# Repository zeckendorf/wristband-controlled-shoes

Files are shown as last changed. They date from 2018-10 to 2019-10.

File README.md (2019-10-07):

# Remote Controlled Shoes

These exist with [some ubiquity](https://www.amazon.com/s?k=led+shoes+with+remote&ref=nb_sb_noss), but at the prompting of a friend I thought it might be fun to design a system that would work more flexibly in different form factors. Ultimately, one device sits as a combination BLE beacon and peripheral that can pair with a phone and transmit the LED state via BLE  advertising packets. 

## Files

**`ble_beacon_remote.ino`**

Device acting as BLE remote that scans for the beacon. Ordinarily this pairs with peripherals, but in this case simply scans for advertising packets, extracts the UUID, and if it is a match for its remote, will sync its state. Deployed to any number of synced devices beyond shoes, e.g. LED headphones synced with music.

**`ble_beacon_origin.ino`**

Device acting as the BLE beacon &mdash; pairs with a control phone as a peripheral to set the button states, and then upon button presses will adjust its state and transmit this information via the BLE beacon `minor` value. BLE beacon architecture is as follows:

* `uuid`: 16-byte identifier for all devices in a given family (e.g. LED shoes). In this case, the first 8-bytes represent the device family and the  second 8-bytes are a unique identifier for this pair.

* `major`: 2-byte device category of paired state (i.e. two shoes, 16 headphones, whatever)
* `minor`: 2-byte system color state

## In Action

*Cycling Through Basics:*

its working

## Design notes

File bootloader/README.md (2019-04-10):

## Arduino Bootloader for NRF52

**Source:**

- [Adafruit Arduino Bootloader Repo](https://github.com/adafruit/Adafruit_nRF52_Arduino_Bootloader)

- [Adafruit NRF52 Arduino Repo](https://github.com/adafruit/Adafruit_nRF52_Arduino)

Thanks eternally for their work getting this chipset in the hands of the people.

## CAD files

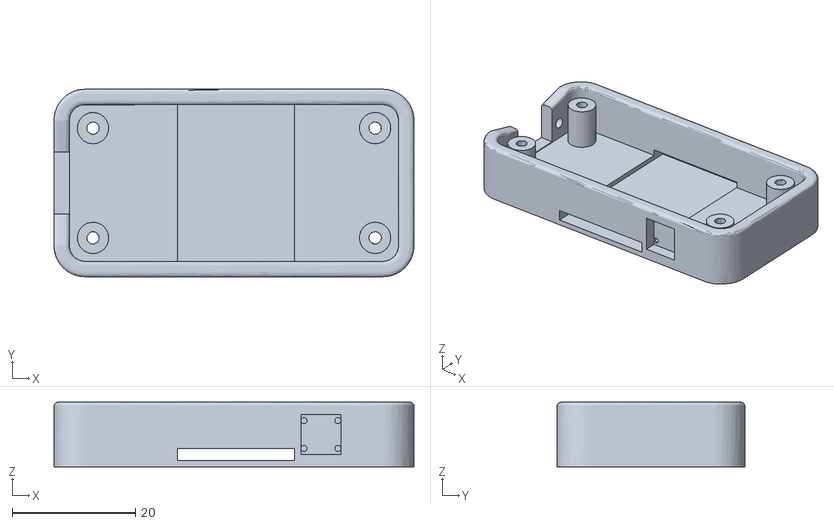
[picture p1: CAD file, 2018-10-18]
design/enclosure/v0/wristband-mount.stl
58.3 x 30.4 x 10.5

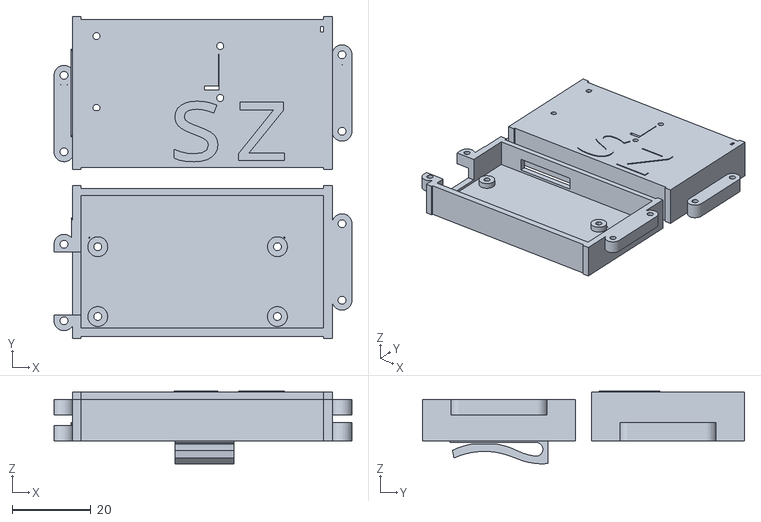
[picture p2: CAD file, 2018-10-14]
design/enclosure/v0/shoe-light-box.stl
75.8 x 82.0 x 18.5

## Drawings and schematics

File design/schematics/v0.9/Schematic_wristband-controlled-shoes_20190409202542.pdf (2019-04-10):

PP3300

PP3300

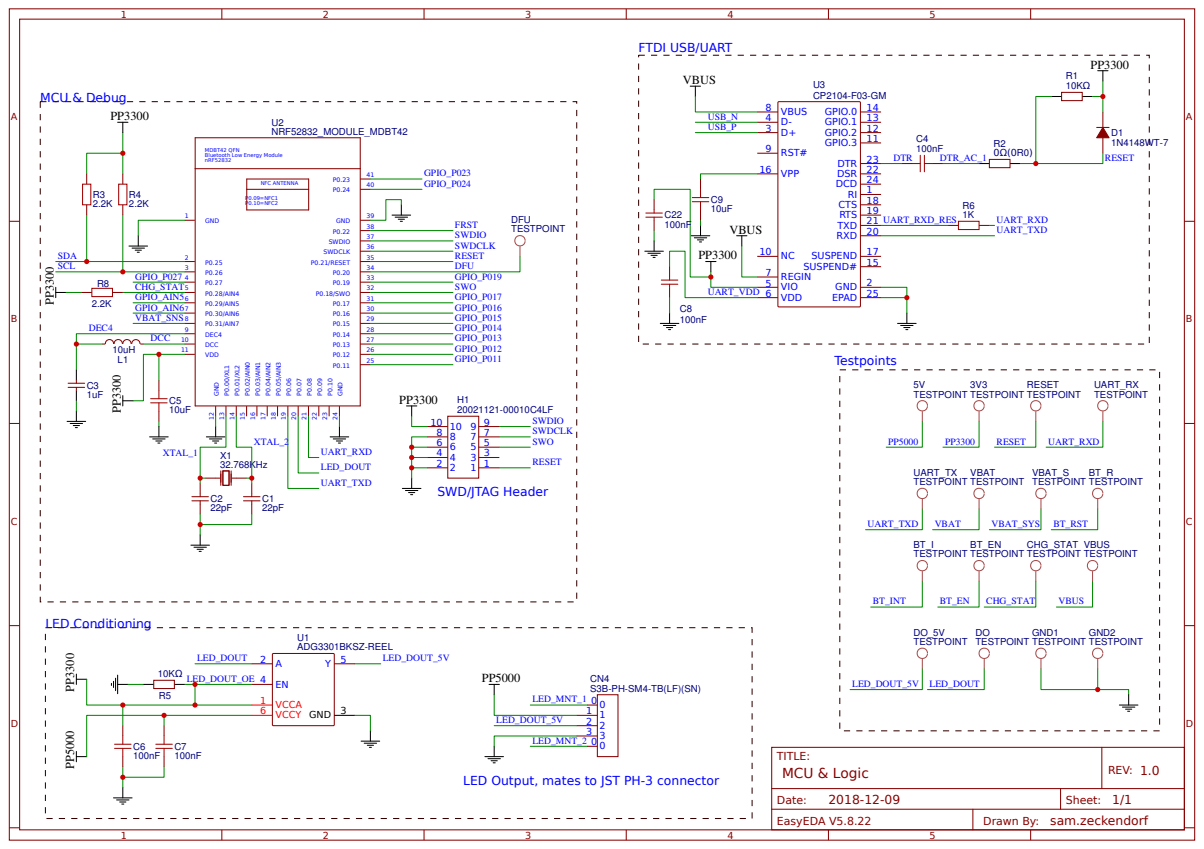
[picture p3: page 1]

24 P0.11 25 P0.12 26 P0.13 27 P0.14 28 P0.15 29 P0.16 30 P0.17 31 P0.18/SWO 32 P0.19 33 P0.20 34 P0.21/RESET 35 SWDCLK 36 SWDIO 37 P0.22 38 GND 39

LED Output, mates to JST PH-3 connector

### VBUS

### VBAT

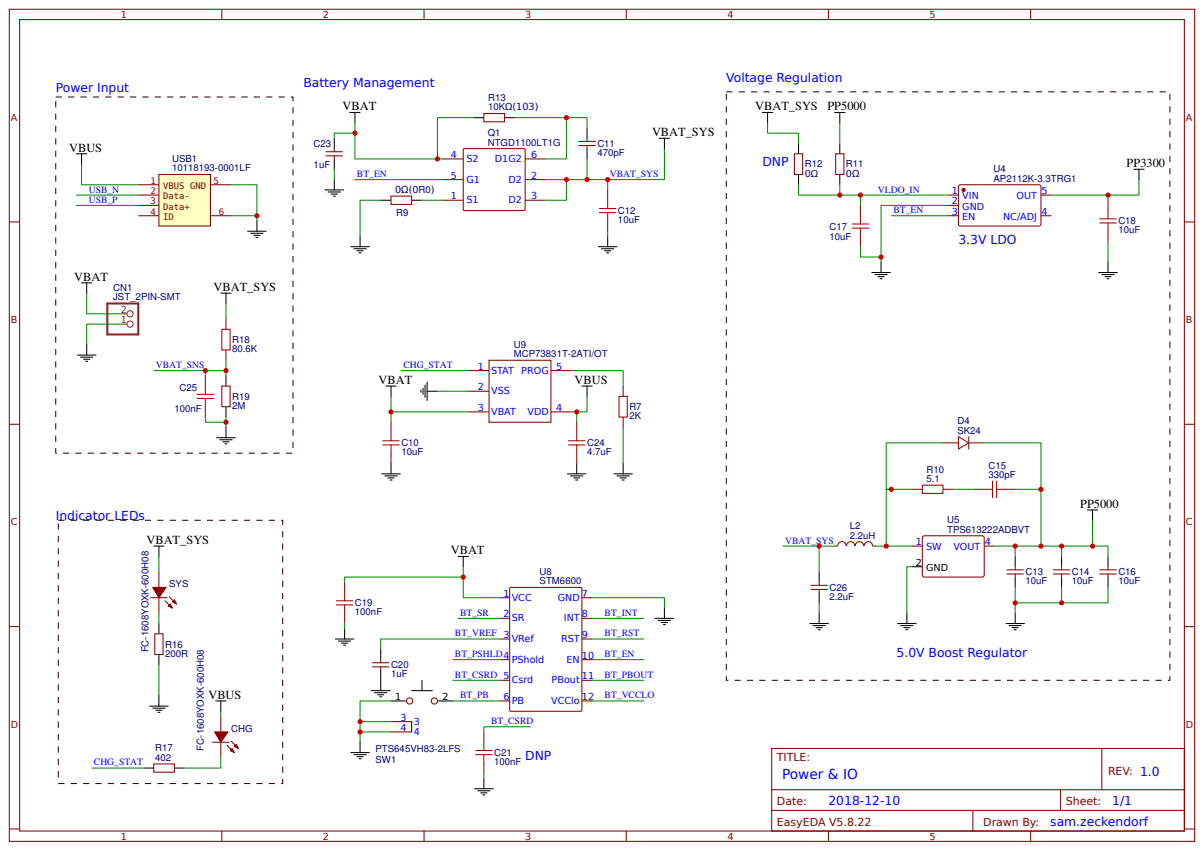
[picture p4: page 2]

Voltage Regulation Battery Management Power Input

Indicator LEDs FC⁻¹⁶⁰⁸YOXK⁻⁶⁰⁰H⁰⁸

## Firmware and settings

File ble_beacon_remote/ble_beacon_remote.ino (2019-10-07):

/*********************************************************************
Author: Sam Zeckendorf
  Date: 10/18/18
  File: ble_beacon_remote.ino

Uses an NRF52 module to sync states with 
 a BLE beacon and illuminate a string of WS2812 RGB LEDs
*********************************************************************/

/* TODO:
    - Get rid of delays in animations by using millis() and frame time modulus
    -
*/

// External libraries from Adafruit
#include <bluefruit.h>
#include <Adafruit_NeoPixel.h>

// Constant definitions -- these offsets within the ble advertising packet 
// are described here (page 10): http://www.ti.com/lit/an/swra475a/swra475a.pdf
// and also here: https://os.mbed.com/blog/entry/BLE-Beacons-URIBeacon-AltBeacons-iBeacon/
#define PIN 7
#define UUID_SIZE 16     //bytes
#define UUID_OFFSET 9    //bytes (Beacon Prefix: 3B flags + 2B header + 2B company ID + 1B secondary ID + 1B length = 9B)
#define ADV_SCAN_SIZE 31 //bytes
#define MINOR_OFFSET 28  //bytes
#define MINOR_SIZE 2     //bytes
#define NUM_LEDS 110
#define PIN_CHG_STAT 28  // digital state of charger pin
#define PIN_VBAT_SNS A7   // analog input of vbat sns 7

// for color data
Adafruit_NeoPixel strip = Adafruit_NeoPixel(NUM_LEDS, PIN, NEO_GRB + NEO_KHZ800);

// state for color
uint16_t state;
bool charging;

// mathematical operations
float adc_voltage;
float vbat_scale;
float vbat;

// time in millis in state
unsigned long time_in_state;
unsigned long duration_in_state; 
unsigned long frames_in_state;

// id of beacon, to be generated via: https://www.uuidgenerator.net/
uint8_t target_uuid[UUID_SIZE] = 
{ 
    0xFF, 0xFF, 0xFF, 0xFF, 0xFF, 0xFF, 0xFF, 0xFF, 
    0xFF, 0xFF, 0xFF, 0xFF, 0xFF, 0xFF, 0xFF, 0xFF, 
};

void setup()
{
  // set scaling
  vbat_scale  = 0.9612; // defined in hardware
  adc_voltage = 3.3;    // volts 
  
  // set up pin modes
  pinMode(PIN_CHG_STAT, INPUT_PULLUP);
  charging = !digitalRead(PIN_CHG_STAT);
  vbat     = measure_battery();
  
  // time setup
  time_in_state     = 0;
  duration_in_state = 0;
  frames_in_state   = 0;
  
  // LED setup
  strip.begin();
  strip.show();

  // BLE setup
  Serial.begin(115200);
  Serial.println("LED Shoe Listening for Wristband Beacon");
  Serial.println("-----------------------------------\n");
  
  // Initialize Bluefruit with maximum connections as Peripheral = 0, Central = 1
  // SRAM usage required by SoftDevice will increase dramatically with number of connections
  Bluefruit.begin(0, 1);
  Bluefruit.setName("LED_SHOE_0x0000");

  // Increase Blink rate to different from PrPh advertising mode
  //Bluefruit.setConnLedInterval(250);

  /* Start Central Scanning
   * - Enable auto scan if disconnected
   * - Interval = 100 ms, window = 80 ms
   * - Don't use active scan
   * - Start(timeout) with timeout = 0 will scan forever (until connected)
   */

  // set up scanner so we can monitor beacon packets
  Bluefruit.Scanner.setRxCallback(scan_callback);
  Bluefruit.Scanner.restartOnDisconnect(true);
  Bluefruit.Scanner.setInterval(160, 80); // in unit of 0.625 ms
  Bluefruit.Scanner.useActiveScan(true); // uses scan response packet as well
  Bluefruit.Scanner.start(0);            // 0 = Don't stop scanning after n seconds
}

float measure_battery()
{
  return analogRead(PIN_VBAT_SNS) / 1024.0 * adc_voltage / vbat_scale;
}

/**
 * Callback invoked when scanner pick up an advertising data
 * @param report Structural advertising data
 */
void scan_callback(ble_gap_evt_adv_report_t* report)
{
  // extract data from report (see nordic api)
  // https://developer.nordicsemi.com/nRF5_SDK/nRF51_SDK_v8.x.x/doc/8.0.0/s110/html/a00225.html
  uint8_t* data     = report->data;
  uint16_t rx_state = 0;
  // pull out uuid from data (slick array slicing using memcpy)
  uint8_t scanned_uuid[UUID_SIZE];
  memcpy(scanned_uuid, &data[UUID_OFFSET], sizeof scanned_uuid);
  
  if (arraysEqual(scanned_uuid, target_uuid, UUID_SIZE))
  { 
    // extract state
    rx_state = data[MINOR_OFFSET];

    // if the state changed, let's do something with it
    if (state != rx_state){
      state = rx_state;
      Serial.print("Shoe Beacon State Updated: ");
      Serial.print(state);
      Serial.print("\n-----------------------------\n");
      time_in_state = millis();
    }
  }
}

// helper function to determine if two arrays are equal
bool arraysEqual(uint8_t* a, uint8_t* b, int len)
{
  for(int i = 0; i < len; i++)
  {
    if(a[i] != b[i])
      return false;
  }
  return true;
}

// used for controlling LEDs
void loop()
{
  charging = !digitalRead(PIN_CHG_STAT);
  vbat     = measure_battery();
  
  // charging state machine
  if(charging){

    // low battery
    if (vbat < 2.7){
      red();
      delay(250);
      none();
      delay(250);
      return;
    }

    // medium battery
    if (vbat < 3.0){
      yellow();
      delay(250);
      none();
      delay(250);
      return;
    }
      // high battery
      green();
      delay(250);
      none();
      delay(250);
      return;
  }
  
  //Serial.println(duration_in_state);
  duration_in_state = millis() - time_in_state;
  if (state == 0x00)
  {
    none();
  }
  else if (state == 0x01)
  {
    red();
  }
  else if (state == 0x02)
  {
    green();
  }
  else if (state == 0x03)
  {
    blue();
  }
  else if (state == 0x04)
  {
    theaterChase(strip.Color(127, 127, 127), 25);
  }
  else if (state == 0x05)
  {
    rainbow(5, duration_in_state);
  }
}

/******************
 ***  LED Code! ***
 ******************/
void none() {
  uint16_t i;
    for(i=0; i<strip.numPixels(); i++) {
      strip.setPixelColor(i, strip.Color(0,0,0));
    }
    strip.show();
}

void red() {
  uint16_t i;
    for(i=0; i<strip.numPixels(); i++) {
      strip.setPixelColor(i, strip.Color(255,0,0));
    }
    strip.show();
}

void blue() {
  uint16_t i;
    for(i=0; i<strip.numPixels(); i++) {
      strip.setPixelColor(i, strip.Color(0,0,255));
    }
    strip.show();
}

void green() {
  uint16_t i;
    for(i=0; i<strip.numPixels(); i++) {
      strip.setPixelColor(i, strip.Color(0,255,0));
    }
    strip.show();
}

void yellow() {
    uint16_t i;
    for(i=0; i<strip.numPixels(); i++) {
      strip.setPixelColor(i, strip.Color(125,125,0));
    }
    strip.show();
}
 
// Fill the dots one after the other with a color
void colorWipe(uint32_t c, uint8_t wait) {
  for(uint16_t i=0; i<strip.numPixels(); i++) {
    strip.setPixelColor(i, c);
    strip.show();
    delay(wait);
  }
}


/*void rainbow(uint8_t wait) {
  uint16_t i, j;

  for(j=0; j<256; j++) {
    for(i=0; i<strip.numPixels(); i++) {
      strip.setPixelColor(i, Wheel((i+j) & 255));
    }
    strip.show();
    delay(wait);
  }
}*/

void rainbow(uint8_t wait, unsigned long t) {
  uint16_t i, j;
  
  // t = time in millis since the state was set to rainbow
  if (t % wait == 0)
    frames_in_state++;
  if (frames_in_state >= 256)
    frames_in_state = 0; 
  j = frames_in_state;
  
  for(i=0; i<strip.numPixels(); i++) {
    strip.setPixelColor(i, Wheel((i+j) & 255));
  }
  strip.show();
  
}

// Slightly different, this makes the rainbow equally distributed throughout
void rainbowCycle(uint8_t wait) {
  uint16_t i, j;

  for(j=0; j<256*5; j++) { // 5 cycles of all colors on wheel
    for(i=0; i< strip.numPixels(); i++) {
      strip.setPixelColor(i, Wheel(((i * 256 / strip.numPixels()) + j) & 255));
    }
    strip.show();
    delay(wait);
  }
}

//Theatre-style crawling lights.
void theaterChase(uint32_t c, uint8_t wait) {
  
  for (int j=0; j<10; j++) {  //do 10 cycles of chasing
    for (int q=0; q < 3; q++) {
      for (uint16_t i=0; i < strip.numPixels(); i=i+3) {
        strip.setPixelColor(i+q, c);    //turn every third pixel on
      }
      strip.show();

      delay(wait);

      for (uint16_t i=0; i < strip.numPixels(); i=i+3) {
        strip.setPixelColor(i+q, 0);        //turn every third pixel off
      }
    }
  }
}

//Theatre-style crawling lights with rainbow effect
void theaterChaseRainbow(uint8_t wait) {
  for (int j=0; j < 256; j++) {     // cycle all 256 colors in the wheel
    for (int q=0; q < 3; q++) {
      for (uint16_t i=0; i < strip.numPixels(); i=i+3) {
        strip.setPixelColor(i+q, Wheel( (i+j) % 255));    //turn every third pixel on
      }
      strip.show();

      delay(wait);

      for (uint16_t i=0; i < strip.numPixels(); i=i+3) {
        strip.setPixelColor(i+q, 0);        //turn every third pixel off
      }
    }
  }
}

// Input a value 0 to 255 to get a color value.
// The colours are a transition r - g - b - back to r.
uint32_t Wheel(byte WheelPos) {
  WheelPos = 255 - WheelPos;
  if(WheelPos < 85) {
    return strip.Color(255 - WheelPos * 3, 0, WheelPos * 3);
  }
  if(WheelPos < 170) {
    WheelPos -= 85;
    return strip.Color(0, WheelPos * 3, 255 - WheelPos * 3);
  }
  WheelPos -= 170;
  return strip.Color(WheelPos * 3, 255 - WheelPos * 3, 0);
}

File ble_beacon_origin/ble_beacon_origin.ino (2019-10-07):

/*********************************************************************
Author: Sam Zeckendorf
  Date: 10/18/18
  File: ble_beacon_origin.ino

Uses the NRF52 module to generate a state based on button presses 
and transmit them to remote sources for illumination of an LED strip
*********************************************************************/

#include <bluefruit.h>
#include <Bounce2.h>

#define MANUFACTURER_ID   0x00E0
#define MAJOR_ID   0xEEFF
#define BUTTON_PIN 7

/* TODO:
 *  - 
 */

uint8_t beaconUuid[16] = 
{ 
  0xFF, 0xFF, 0xFF, 0xFF, 0xFF, 0xFF, 0xFF, 0xFF, 
  0xFF, 0xFF, 0xFF, 0xFF, 0xFF, 0xFF, 0xFF, 0xFF, 
};

// global vars
BLEBeacon beacon;
uint16_t state;
Bounce debouncer = Bounce(); // Instantiate a Bounce object

void setup()
{
  // BLE setup
  Serial.begin(115200);
  Serial.println("Wristband Beacon for LED Shoe");
  Bluefruit.begin();
  Bluefruit.setName("LED_WB_0x0000");
  Bluefruit.setTxPower(4); 

  // Initialize beacon with state in the minor packet
  state = 0x00;
  initBeacon();

  // Init button reader
  debouncer.attach(BUTTON_PIN, INPUT_PULLUP); // Attach the debouncer to a pin with INPUT_PULLUP mode
  debouncer.interval(25); // Use a debounce interval of 25 milliseconds
  
}

void loop()
{
  // get button state
  debouncer.update(); // Update the Bounce instance

  // use serial port to set state
  receiveSerial();
  
  if ( debouncer.fell() ) {  // Call code if button transitions from HIGH to LOW
     
     state += 1;
     
     if (state > 5) 
      state = 0;

      // reinit beacon every loop (realistically should only do this when state changes)
      initBeacon();
      
     Serial.print("Current State: ");
     Serial.println(state, DEC);
   }
}

void receiveSerial(){
  
    // send data only when you receive data:
    if (Serial.available() > 0) {
            // read the incoming byte:
            state = Serial.parseInt();

            // say what you got:
            Serial.print("Current State: ");
            Serial.println(state, DEC);
    }
}
/*------------------------------------------------------------------*/
/* Beacon!
 *------------------------------------------------------------------*/

void initBeacon()
{
  // initialize beacon, accounts for changing state
  beacon = BLEBeacon(beaconUuid, MAJOR_ID, state, -24);
    
  // Manufacturer ID is required for Manufacturer Specific Data
  beacon.setManufacturer(MANUFACTURER_ID);
  setupAdv();
}

void setupAdv(void)
{  
  // Set the beacon payload using the BLEBeacon class populated
  // earlier in this example
  Bluefruit.Advertising.setBeacon(beacon);

  // Start advertising
  Bluefruit.Advertising.start();
}

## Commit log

2018-09-21 added ble arduino scripts for wristband and shoe
2018-09-25 added project enclosure stl files
    [shoe-light-box.stl]
2018-09-25 added usb porting to enclosure
    [shoe-light-box.stl]
2018-09-25 added clip to enclosure
    [shoe-light-box.stl]
2018-10-03 updated project enclosure to increase the usb porting size and add some clearance for clip
    [shoe-light-box.stl]
2018-10-03 updated project enclosure to to add some Z for battery fitment and room for wires
    [shoe-light-box.stl]
2018-10-03 added switch to enclosure
    [shoe-light-box.stl]
2018-10-03 added switch to enclosure (SS12F15G3)
    [shoe-light-box.stl]
2018-10-03 moved switch to larger side w/ more room to avoid battery
    [shoe-light-box.stl]
2018-10-14 updated wristband firmware to take serial input, updated shoe firmware with correct number of LEDs
2018-10-14 added wristband mount stl file
    [wristband-mount.stl]
2018-10-15 updated wrist enclosure to add on/off switch
    [wristband-mount.stl]
2018-10-18 added button logic using Button2 arduino library (https://github.com/thomasfredericks/Bounce2) so I don't have to do all that debouncing logic myself
2018-10-18 updated wristband mount to fix switch mount position and USB porting
    [wristband-mount.stl]
2019-04-10 updated file structure, added pcb design documents and bootloader
    [shoe-board-pcb.pcbdoc, shoe-light-box.stl, wristband-mount.stl]
2019-06-10 Updated transmit power to maximum of +4dB
2019-09-09 Add schematic for posterity
